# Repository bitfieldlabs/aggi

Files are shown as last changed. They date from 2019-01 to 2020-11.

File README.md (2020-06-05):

afterglow Afterglow GI

AFTERGLOW GI is a WPC pinball machine extension board that aims at softening the hard light on/off transitions that result in replacing the original GI incandescent bulbs with LEDs.

The brain of the board is a Arduino nano. It monitors the triac signals on the WPC bus and adjusts the PWM of the GI lines accordingly in order to dim the LEDs. For this purpose the whole GI is powered on DC voltage as opposed to the original AC 6.3V.

There are two options to power the Afterglow GI board and all GI LEDs:

:open_file_folder: [afterglow_gi_nano](https://github.com/bitfieldlabs/aggi/tree/master/afterglow_gi_nano)<br>
Board revision 1.0 needs to be powered from an external power supply. Recommended is a 12V supply delivering at least 8A.

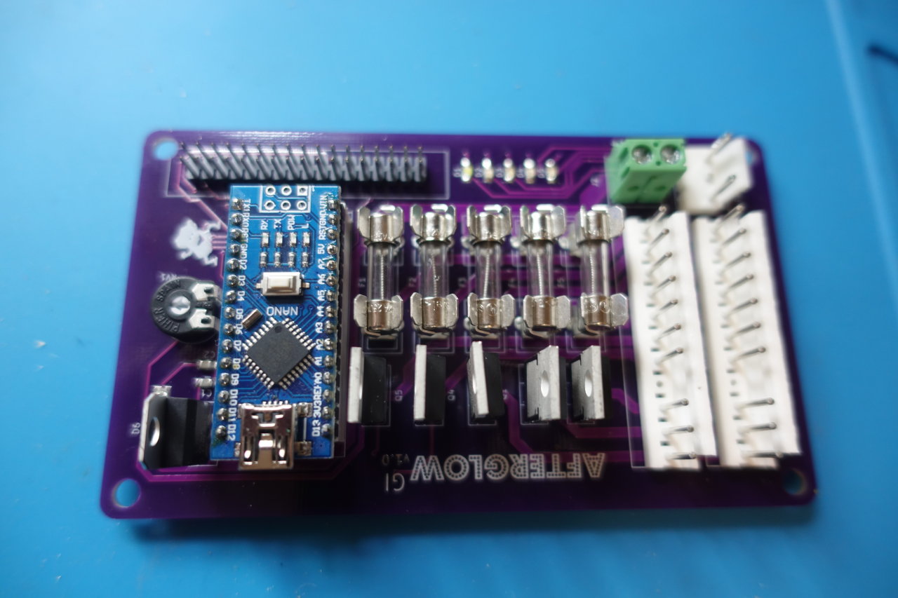
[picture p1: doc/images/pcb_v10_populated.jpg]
afterglow GI Afterglow GI v1.0


:open_file_folder: [afterglow_gi_nano_ps](https://github.com/bitfieldlabs/aggi/tree/master/afterglow_gi_nano_ps)<br>
Board revision 1.1 features a power supply and can be attached to the WPC power supply's 6.3V AC connector directly.

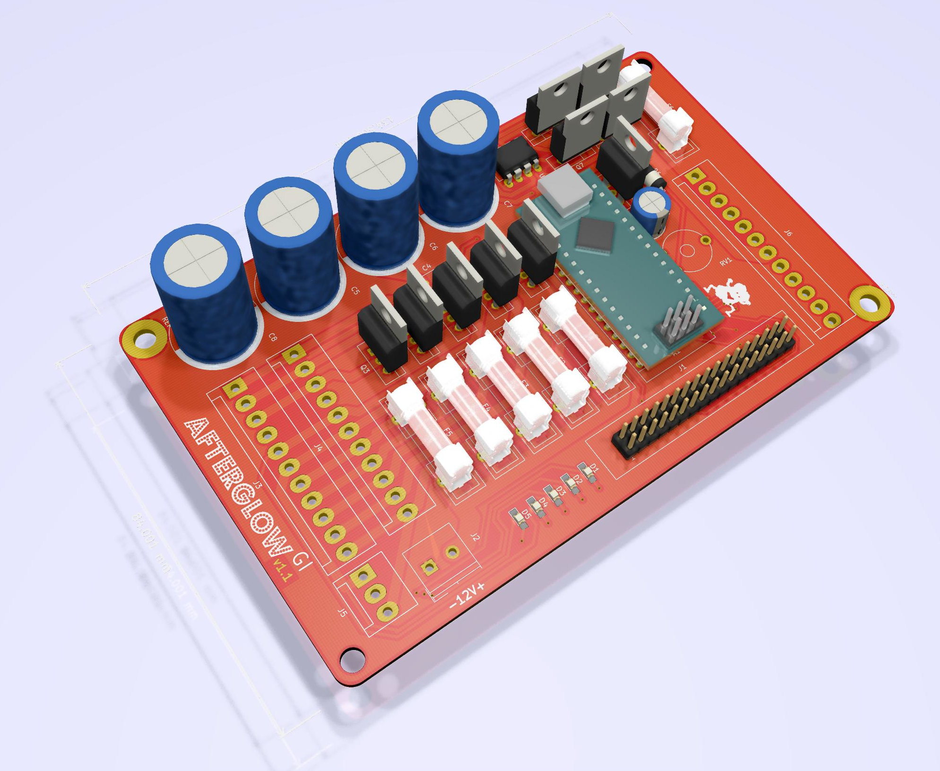
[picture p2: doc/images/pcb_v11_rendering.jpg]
afterglow GI Afterglow GI v1.1


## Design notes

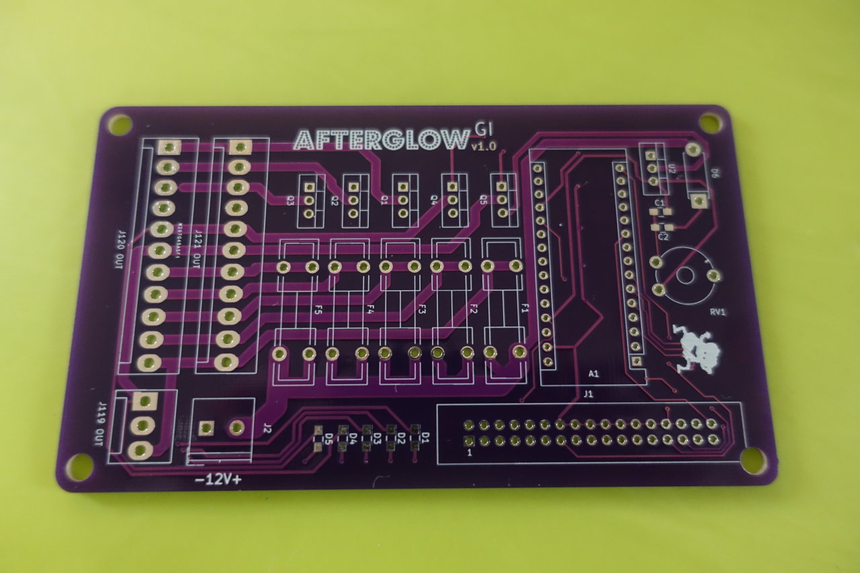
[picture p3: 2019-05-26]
doc/images/pcb_v10_unpopulated.jpg

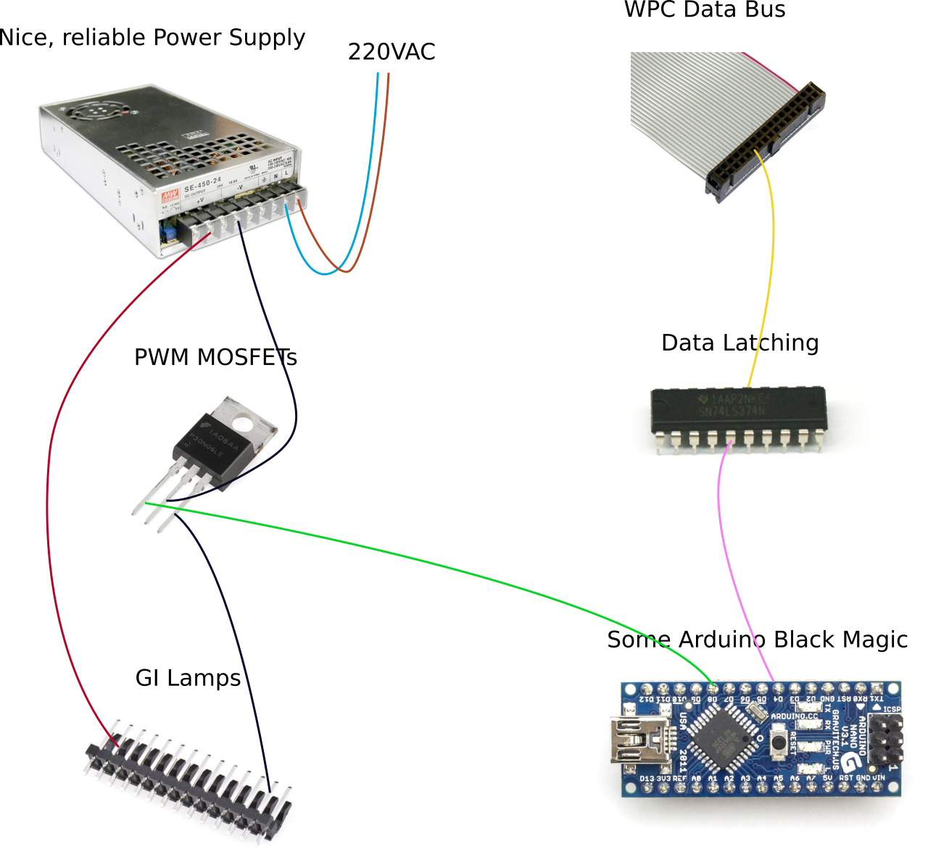
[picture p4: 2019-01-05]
doc/idea.png

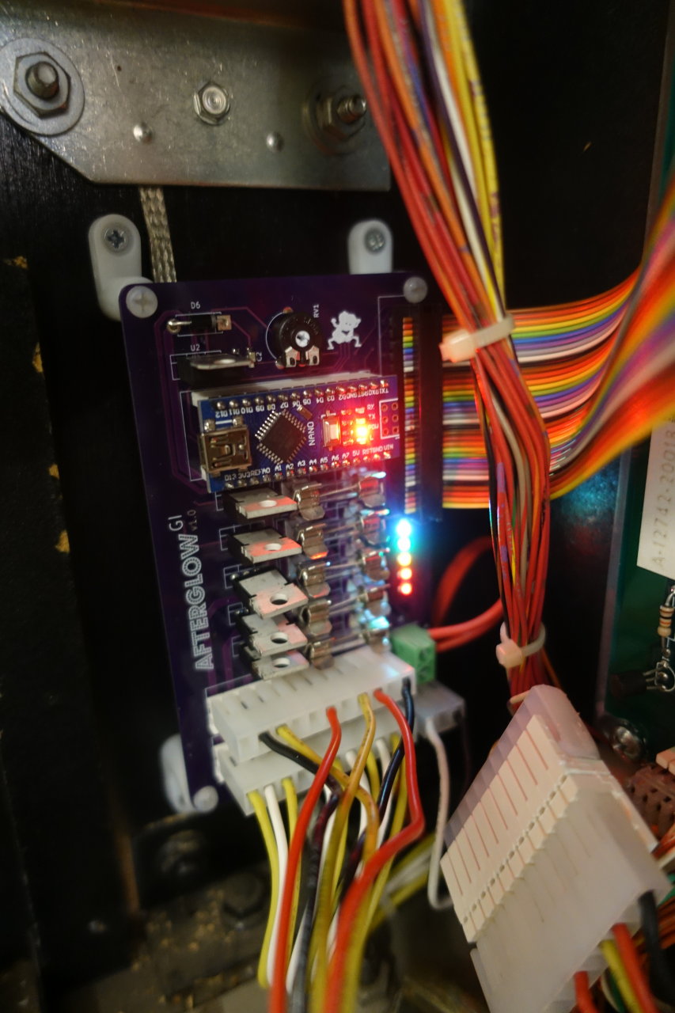
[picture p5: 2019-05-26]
doc/images/pcb_v10_mounted_1.jpg

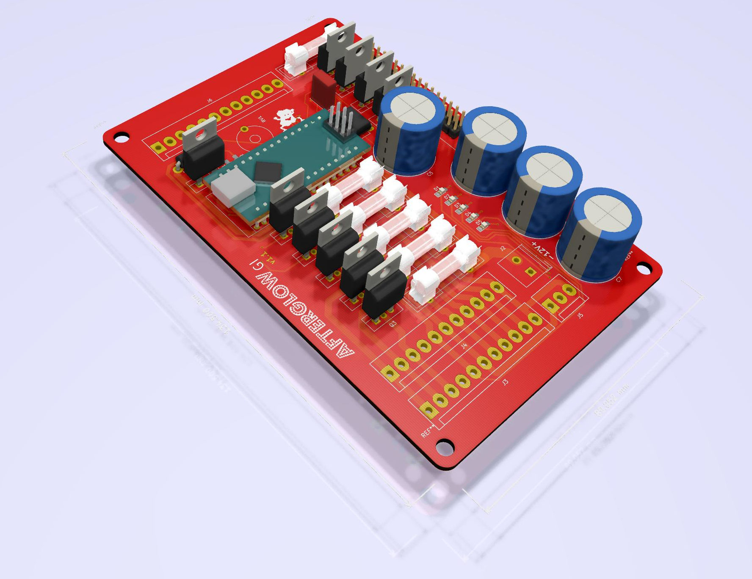
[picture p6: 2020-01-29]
doc/afterglow_gi_nano_ps.jpg

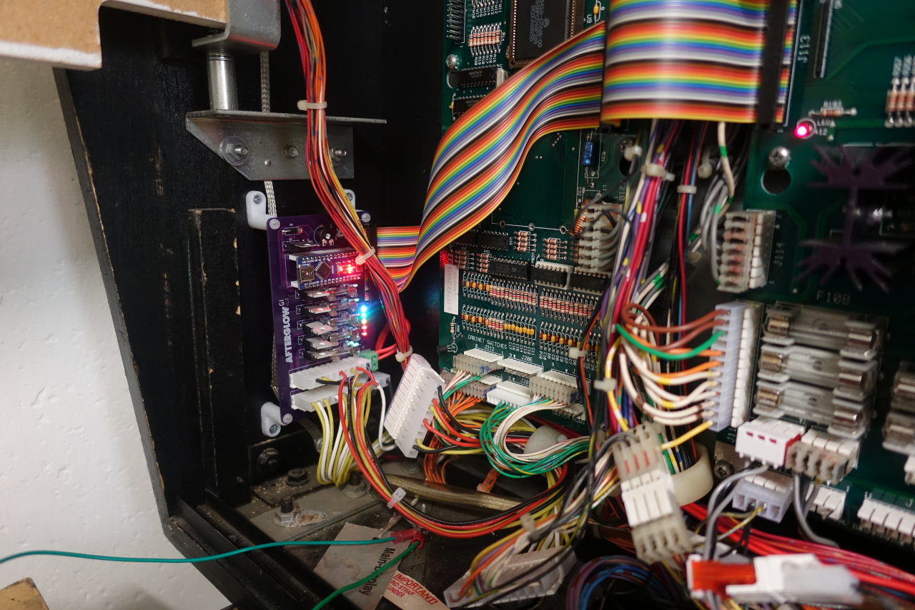
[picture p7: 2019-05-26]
doc/images/pcb_v10_mounted_2.jpg

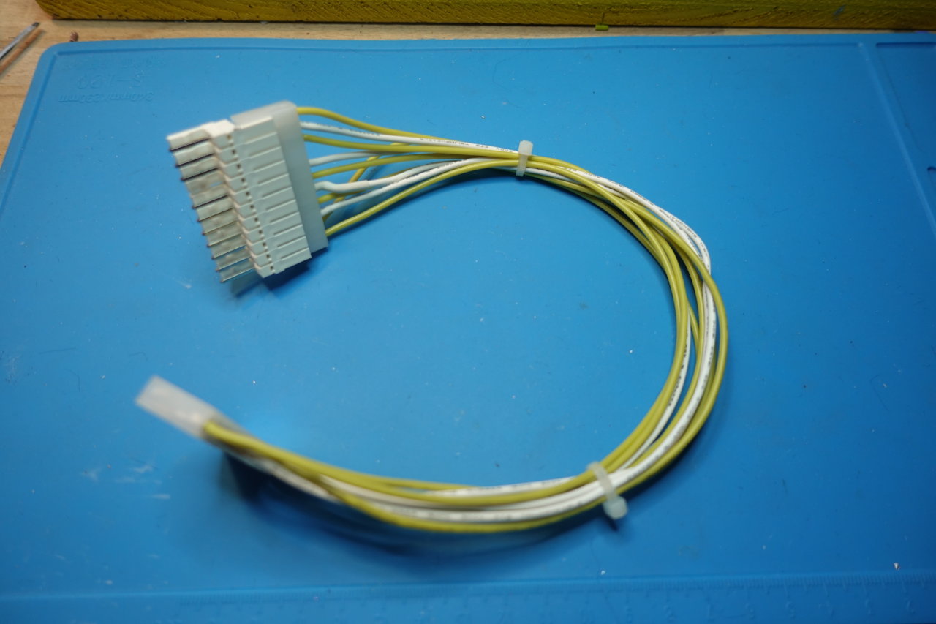
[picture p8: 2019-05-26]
doc/images/cable_extension_11pin_with_zconnector.jpg

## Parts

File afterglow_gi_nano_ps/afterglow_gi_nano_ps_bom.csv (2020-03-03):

Id | Designator | Package | Quantity | Designation | Supplier and ref
1 | C9 | CP_Radial_D8.0mm_P3.50mm | 1 | 100uF
2 | REF**,REF** | MountingHole_4.3mm_M4_Pad | 2 | MountingHole_4.3mm_M4_Pad
3 | C4 | C_Rect_L7.0mm_W3.5mm_P5.00mm | 1 | 1uF
4 | U3 | DIP-8_W7.62mm_LongPads | 1 | LT4320_CAP
5 | Q9,Q8,Q7,Q6,Q1,Q2,Q3,Q4,Q5 | TO-220_Vertical | 9 | FQP30N06L
6 | J6 | Molex_KK-41791-12_10x3.96mm_Straight | 1 | Conn_01x12_Male
7 | F6,F1,F2,F3,F4,F5 | Fuseholder5x20_horiz_open_lateral_Type-II | 6 | Fuse
8 | C8,C7,C6,C5 | CP_Radial_D18.0mm_P7.50mm | 4 | 5600uF
9 | , | MountingHole_4.3mm_M4_DIN965 | 2 | MountingHole_4.3mm_M4_DIN965
10 | RV1 | Potentiometer_Trimmer_Piher_PT-10v10_Horizontal_Px10.0mm_Py5.0mm | 1 | R_POT_TRIM
11 | J2 | TerminalBlock_Philmore_TB132_02x5mm_Straight | 1 | POWER_CONN
12 | U1 | SOIC-20W_7.5x12.8mm_Pitch1.27mm | 1 | 74LS374
13 | A1 | Arduino_Nano | 1 | Arduino_Nano_v3.x
14 | C1 | C_0805_HandSoldering | 1 | C_Small
15 | C2 | C_0805_HandSoldering | 1 | 0.33u
16 | C3 | C_0805_HandSoldering | 1 | 0.1u
17 | D1,D2,D3,D4,D5 | LED_0805_HandSoldering | 5 | LED
18 | D6 | D_5W_P10.16mm_Horizontal | 1 | D
19 | J1 | IDC_Header_Straight_34pins | 1 | Conn_02x17_Odd_Even
20 | J3 | Molex_KK-41791-11_10x3.96mm_Straight | 1 | GI_WPC_J120
21 | J4 | Molex_KK-41791-11_10x3.96mm_Straight | 1 | GI_WPC_J121
22 | J5 | Molex_KK-41791-03_03x3.96mm_Straight | 1 | GI_CONN_J119
23 | R1,R3,R5,R6,R8,R9,R11,R12,R14,R15,R17 | R_0805_HandSoldering | 11 | 10k
24 | R2 | R_0805_HandSoldering | 1 | 1.5k
25 | R4,R7,R10,R13,R16,R21,R22 | R_0805_HandSoldering | 7 | 220
26 | R18,R19,R20 | R_0805_HandSoldering | 3 | 180
27 | R23 | R_0805_HandSoldering | 1 | 1M
28 | R24 | R_0805_HandSoldering | 1 | 300k
29 | U2 | TO-220_Vertical | 1 | L7805
30 | FLAKIE | FLAKIE_inv | 1
31 | afterglow | afterglow | 1

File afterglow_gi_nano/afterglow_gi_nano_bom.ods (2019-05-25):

Source: | /home/smyp/data/elektronikbaschtel/aggi/afterglow_gi_nano/afterglow_gi_nano.sch
Date: | So 05 Mai 2019 08:55:42 CEST
Tool: | Eeschema 5.1.2
Generator: | /usr/share/kicad/plugins/bom_csv_grouped_by_value_with_fp.py
Component Count: | 52
Ref | Qnty | Value | Description
A1, | 1 | Arduino_Nano_v3.x | Arduino Nano v3.x
C1, | 1 | 0.1u | Unpolarized capacitor, small symbol
C2, | 1 | 0.33u | Unpolarized capacitor, small symbol
C3, | 1 | 0.1u | Unpolarized capacitor, small symbol
D1, D2, D3, D4, D5, | 5 | LED | Light emitting diode
D6, | 1 | D | Diode
F1, F2, F3, F4, F5, | 5 | Fuse | Fuse
J1, | 1 | Conn_02x17_Odd_Even | Generic connector, double row, 02x17, odd/even pin numbering scheme (row 1 odd numbers, row 2 even numbers), script generated (kicad-library-utils/schlib/autogen/connector/)
J2, | 1 | POWER_CONN | Generic connector, single row, 01x02, script generated (kicad-library-utils/schlib/autogen/connector/)
J3, | 1 | GI_WPC_J120 | Generic connector, single row, 01x11, script generated (kicad-library-utils/schlib/autogen/connector/)
J4, | 1 | GI_WPC_J121 | Generic connector, single row, 01x11, script generated (kicad-library-utils/schlib/autogen/connector/)
J5, | 1 | GI_CONN_J119 | Generic connector, single row, 01x03, script generated (kicad-library-utils/schlib/autogen/connector/)
Q1, Q2, Q3, Q4, Q5, | 5 | FQP30N06L | MOSFET N-CH 60V 32A TO-220
R1, R5, R3, R8, R6, R11, R9, R14, R12, R17, R15, | 11 | 10k | Resistor
R2, | 1 | 1.5k | Resistor
R18, R19, R20, | 3 | 180 | Resistor
R21, R22, R4, R7, R10, R13, R16, | 7 | 220 | Resistor
R23, | 1 | 1M | Resistor
R24, | 1 | 300k | Resistor
RV1, | 1 | R_POT_TRIM | Trim-potentiometer
U1, | 1 | 74LS374 | 8-bit Register, 3-state outputs
U2, | 1 | L7805 | Positive 1.5A 35V Linear Regulator, Fixed Output 5V, TO-220/TO-263/TO-252

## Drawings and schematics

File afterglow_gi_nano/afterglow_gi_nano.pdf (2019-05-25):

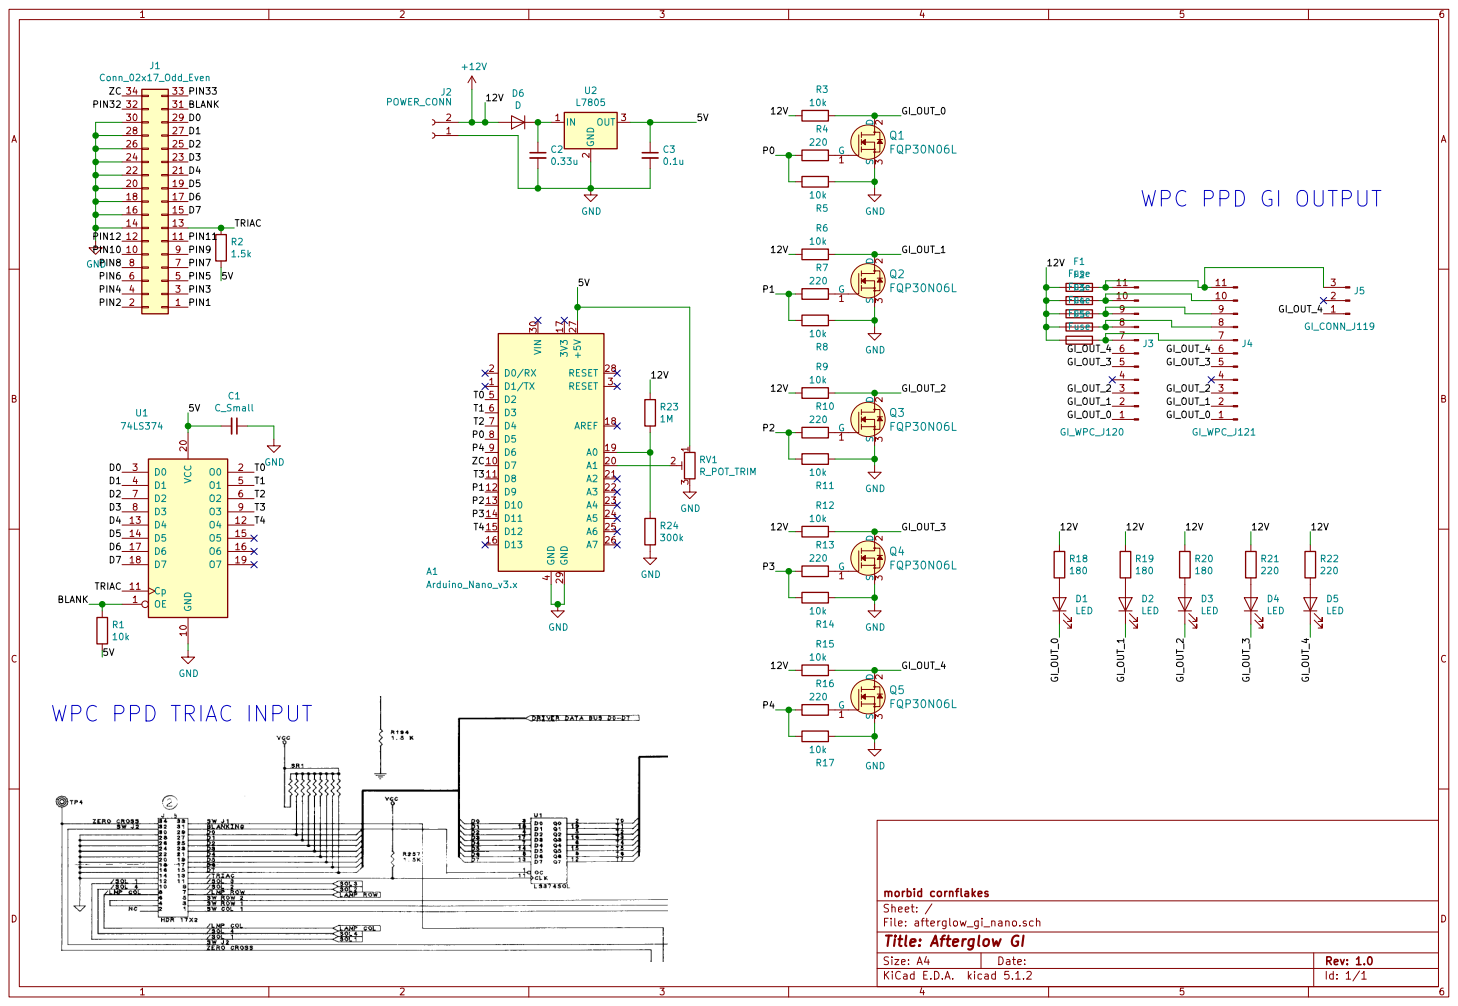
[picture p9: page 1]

ZC GND 26 | 25

24 | 23
22 | 21
20 | 19
18 | 17

WPC PPD GI OUTPUT

F2 Fuse F3 Fuse F4 Fuse F5 Fuse

4 D2 5 D3 6 D4 7 D5 8 D6 9 A1Arduino_Nano_v3.x OE 1 GND 10
P0P1P2P3P4 WPC PPD TRIAC INPUT
D0 D1 D2 D3 D4 D5 D6 D7 BLANK

File: afterglow_gi_nano.sch Sheet: / morbid cornflakes

Id: 1/1 Title: Afterglow GI

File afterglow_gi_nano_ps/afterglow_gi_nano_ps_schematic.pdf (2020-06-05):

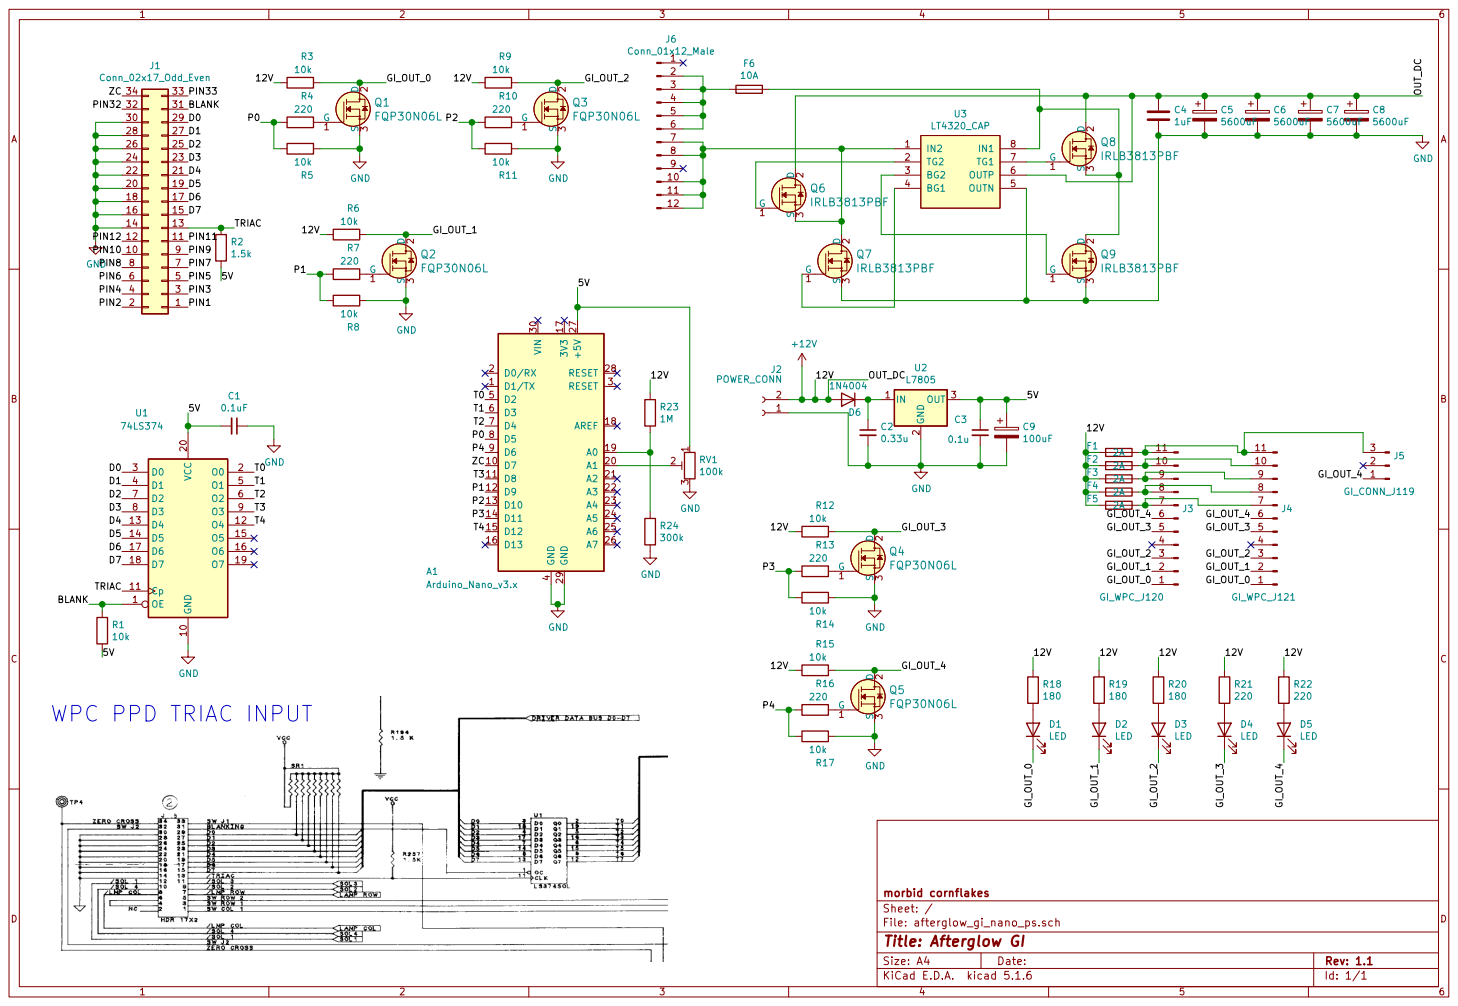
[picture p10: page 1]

J6 Conn_01x12_Male
P0 WPC PPD TRIAC INPUT

22 | 21
20 | 19
18 | 17
16 | 15
14 | 13

File: afterglow_gi_nano_ps.sch Sheet: / morbid cornflakes

Id: 1/1 Title: Afterglow GI

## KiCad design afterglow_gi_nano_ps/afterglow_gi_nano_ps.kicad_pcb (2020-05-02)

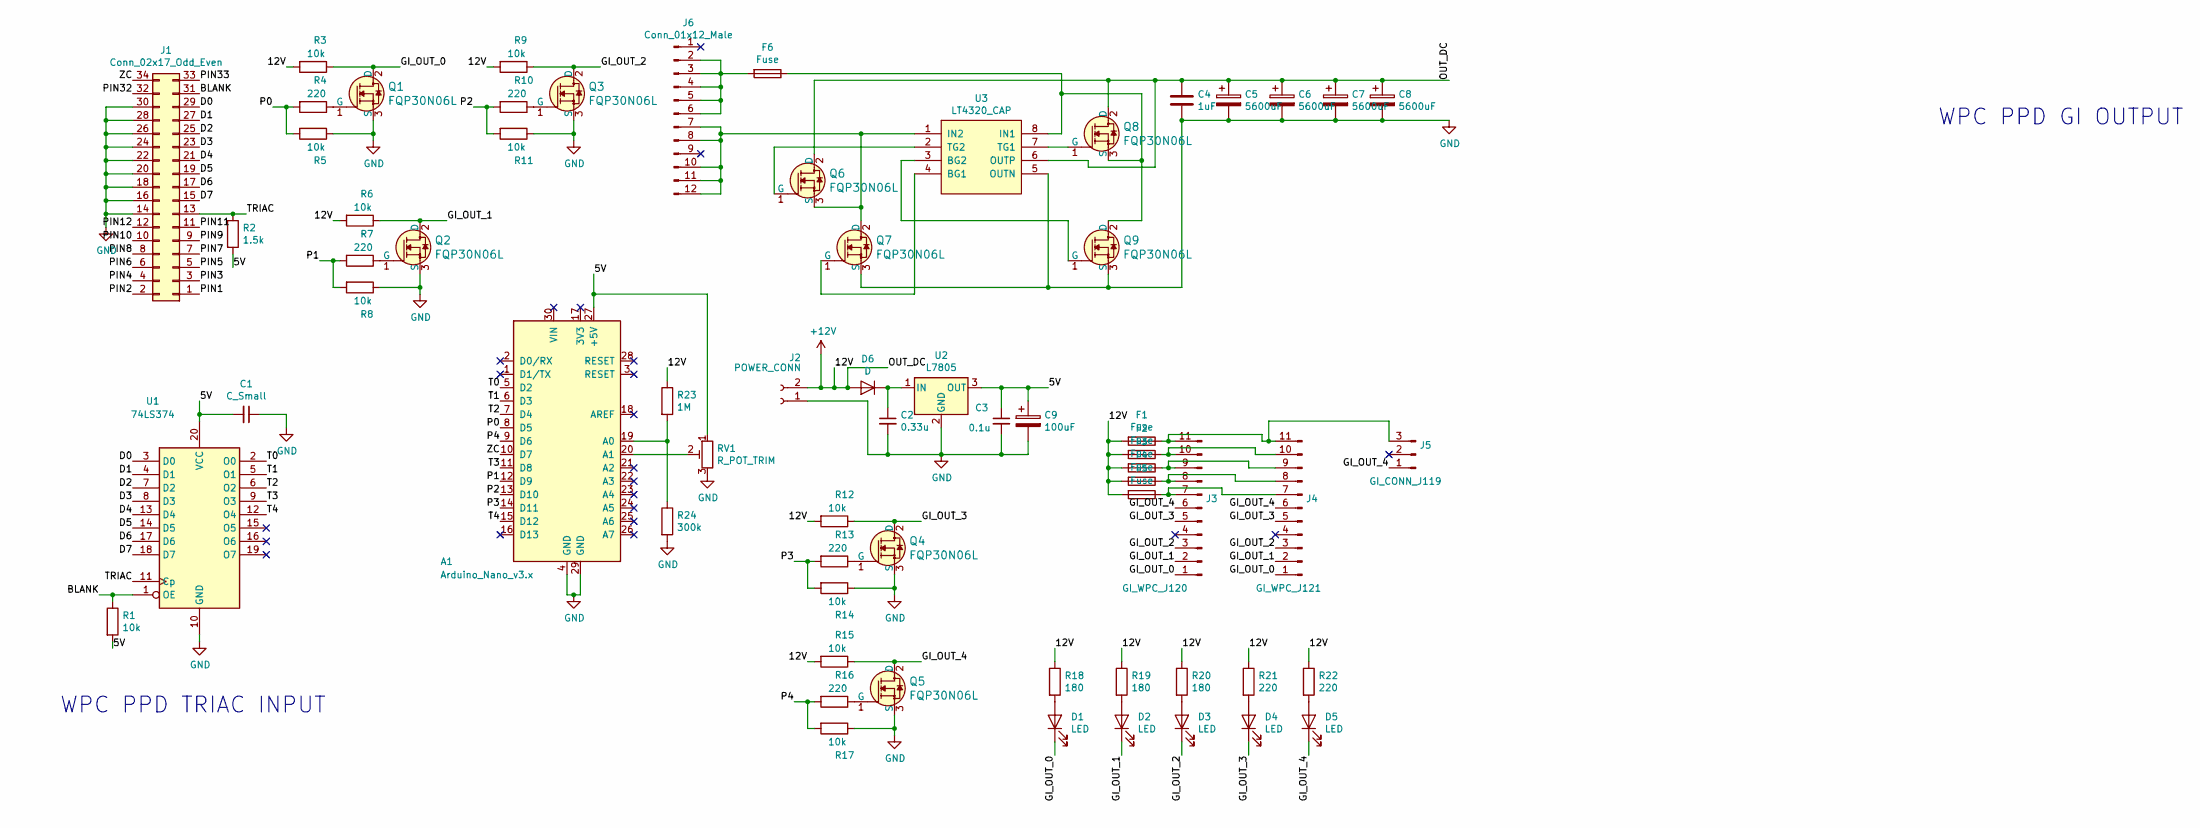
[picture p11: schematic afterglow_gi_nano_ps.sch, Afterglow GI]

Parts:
A1: Arduino_Nano_v3.x; Arduino_Nano
C1: C_Small; C_0805_HandSoldering
C2: 0.33u; C_0805_HandSoldering
C3: 0.1u; C_0805_HandSoldering
C4: 1uF; C_Rect_L7.0mm_W3.5mm_P5.00mm
C5, C6, C7, C8: 5600uF; CP_Radial_D18.0mm_P7.50mm
C9: 100uF; CP_Radial_D8.0mm_P3.50mm
D1, D2, D3, D4, D5: LED; LED_0805_HandSoldering
D6: D; D_5W_P10.16mm_Horizontal
F1, F2, F3, F4, F5, F6: Fuse; Fuseholder5x20_horiz_open_lateral_Type-II
J1: Conn_02x17_Odd_Even; IDC_Header_Straight_34pins
J2: POWER_CONN; TerminalBlock_Philmore_TB132_02x5mm_Straight
J3: GI_WPC_J120; Molex_KK-41791-11_10x3.96mm_Straight
J4: GI_WPC_J121; Molex_KK-41791-11_10x3.96mm_Straight
J5: GI_CONN_J119; Molex_KK-41791-03_03x3.96mm_Straight
J6: Conn_01x12_Male; Molex_KK-41791-12_10x3.96mm_Straight
Q1, Q2, Q3, Q4, Q5, Q6, Q7, Q8, Q9: FQP30N06L; TO-220_Vertical; MPN FQP30N06L; Digi-Key_PN FQP30N06L-ND
R1, R3, R5, R6, R8, R9, R11, R12, R14, R15, R17: 10k; R_0805_HandSoldering
R2: 1.5k; R_0805_HandSoldering
R4, R7, R10, R13, R16, R21, R22: 220; R_0805_HandSoldering
R18, R19, R20: 180; R_0805_HandSoldering
R23: 1M; R_0805_HandSoldering
R24: 300k; R_0805_HandSoldering
RV1: R_POT_TRIM; Potentiometer_Trimmer_Piher_PT-10v10_Horizontal_Px10.0mm_Py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
U1: 74LS374; SOIC-20W_7.5x12.8mm_Pitch1.27mm
U2: L7805; TO-220_Vertical
U3: LT4320_CAP; DIP-8_W7.62mm_LongPads

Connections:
+12V: C4.1, C5.1, C6.1, C7.1, C8.1, D6.2 (A), F1.2, F2.2, F3.2, F4.2, F5.2, J2.2, Q6.2 (D), Q8.2 (D), R3.2, R6.2, R9.2, R12.2, R15.2, R18.1, R19.1, R20.1, R21.1, R22.1, R23.1, U3.6 (OUTP)
/5V: A1.27 (+5V), C1.2, C3.1, C9.1, R1.2, R2.2, RV1.1, U1.20 (VCC), U2.3 (OUT)
/BLANK: J1.31, R1.1, U1.1 (OE)
/D0: J1.29, U1.3 (D0)
/D1: J1.27, U1.4 (D1)
/D2: J1.25, U1.7 (D2)
/D3: J1.23, U1.8 (D3)
/D4: J1.21, U1.13 (D4)
/D5: J1.19, U1.14 (D5)
/D6: J1.17, U1.17 (D6)
/D7: J1.15, U1.18 (D7)
/GI_OUT_0: D1.1 (K), J3.1, J4.1, Q1.2 (D), R3.1
/GI_OUT_1: D2.1 (K), J3.2, J4.2, Q2.2 (D), R6.1
/GI_OUT_2: D3.1 (K), J3.3, J4.3, Q3.2 (D), R9.1
/GI_OUT_3: D4.1 (K), J3.5, J4.5, Q4.2 (D), R12.1
/GI_OUT_4: D5.1 (K), J3.6, J4.6, J5.1, Q5.2 (D), R15.1
/P0: A1.8 (D5), R4.2, R5.2
/P1: A1.12 (D9), R7.2, R8.2
/P2: A1.13 (D10), R10.2, R11.2
/P3: A1.14 (D11), R13.2, R14.2
/P4: A1.9 (D6), R16.2, R17.2
/PIN1: J1.1
/PIN2: J1.2
/PIN3: J1.3
/PIN4: J1.4
/PIN5: J1.5
/PIN6: J1.6
/PIN7: J1.7
/PIN8: J1.8
/PIN9: J1.9
/PIN10: J1.10
/PIN11: J1.11
/PIN12: J1.12
/PIN32: J1.32
/PIN33: J1.33
/T0: A1.5 (D2), U1.2 (O0)
/T1: A1.6 (D3), U1.5 (O1)
/T2: A1.7 (D4), U1.6 (O2)
/T3: A1.11 (D8), U1.9 (O3)
/T4: A1.15 (D12), U1.12 (O4)
/TRIAC: J1.13, R2.1, U1.11 (Cp)
/ZC: A1.10 (D7), J1.34
GND: A1.4 (GND), A1.29 (GND), C1.1, C2.2, C3.2, C4.2, C5.2, C6.2, C7.2, C8.2, C9.2, J1.14, J1.16, J1.18, J1.20, J1.22, J1.24, J1.26, J1.28, J1.30, J2.1, Q1.3 (S), Q2.3 (S), Q3.3 (S), Q4.3 (S), Q5.3 (S), Q7.3 (S), Q9.3 (S), R5.1, R8.1, R11.1, R14.1, R17.1, R24.2, RV1.3, U1.10 (GND), U2.2 (GND), U3.5 (OUTN)
unnamed: A1.19 (A0), R23.2, R24.1
unnamed: A1.20 (A1), RV1.2
unnamed: C2.1, D6.1 (K), U2.1 (IN)
unnamed: D1.2 (A), R18.2
unnamed: D2.2 (A), R19.2
unnamed: D3.2 (A), R20.2
unnamed: D4.2 (A), R21.2
unnamed: D5.2 (A), R22.2
unnamed: F1.1, J3.11, J4.11, J5.3
unnamed: F2.1, J3.10, J4.10
unnamed: F3.1, J3.9, J4.9
unnamed: F4.1, J3.8, J4.8
unnamed: F5.1, J3.7, J4.7
unnamed: F6.1, Q8.3 (S), Q9.2 (D), U3.8 (IN1)
unnamed: F6.2, J6.2, J6.3, J6.4, J6.5, J6.6
unnamed: J6.7, J6.8, J6.10, J6.11, J6.12, Q6.3 (S), Q7.2 (D), U3.1 (IN2)
unnamed: Q1.1 (G), R4.1
unnamed: Q2.1 (G), R7.1
unnamed: Q3.1 (G), R10.1
unnamed: Q4.1 (G), R13.1
unnamed: Q5.1 (G), R16.1
unnamed: Q6.1 (G), U3.2 (TG2)
unnamed: Q7.1 (G), U3.4 (BG1)
unnamed: Q8.1 (G), U3.7 (TG1)
unnamed: Q9.1 (G), U3.3 (BG2)

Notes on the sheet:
WPC PPD TRIAC INPUT
WPC PPD GI OUTPUT

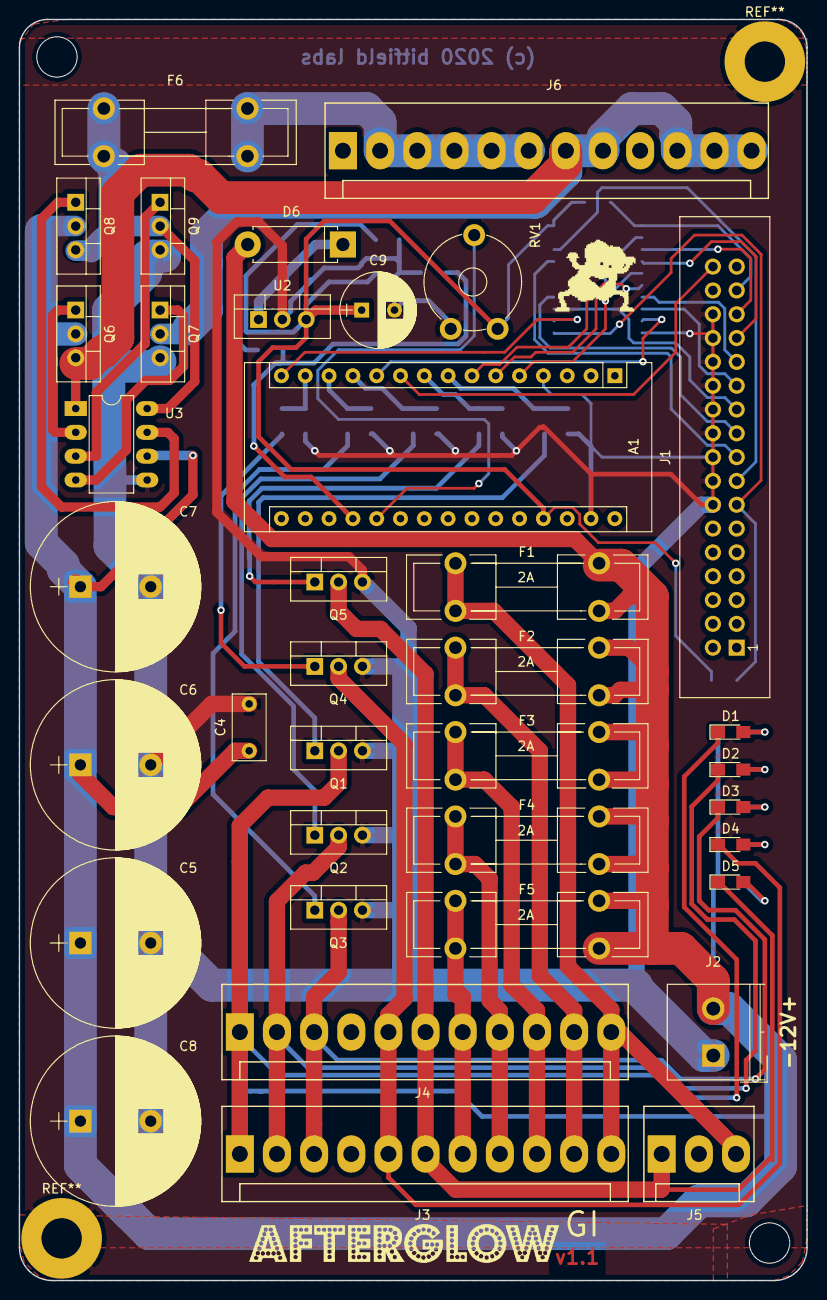
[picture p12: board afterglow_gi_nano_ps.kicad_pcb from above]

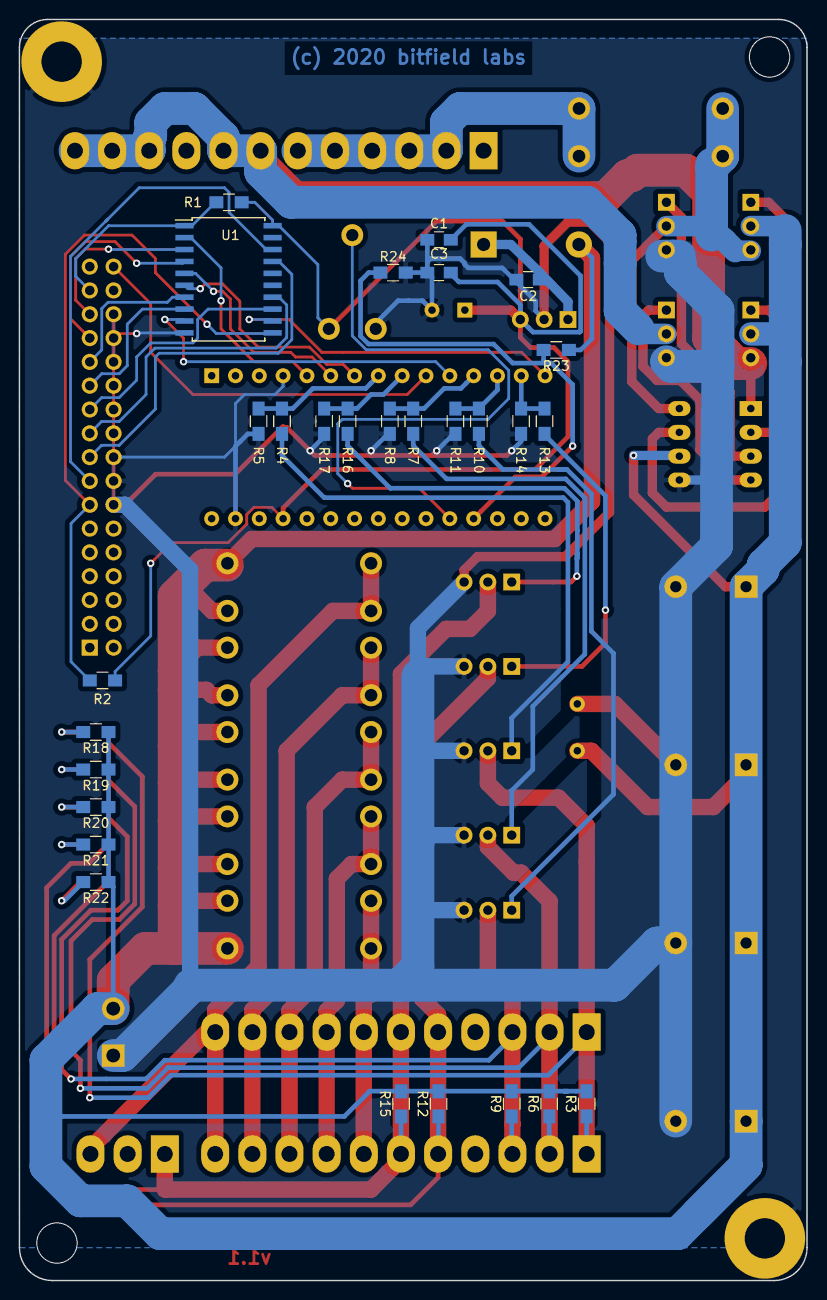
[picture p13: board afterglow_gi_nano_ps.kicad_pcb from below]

Board: 2 copper layers, 84.0 x 134.5 mm, 67 parts (28 on the bottom side), 54 nets.

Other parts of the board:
FLAKIE: FLAKIE_inv
afterglow: afterglow

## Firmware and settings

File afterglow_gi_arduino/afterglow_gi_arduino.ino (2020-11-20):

/***********************************************************************
 *  Afterglow GI:
 *      Copyright (c) 2019 Christoph Schmid
 *
 ***********************************************************************
 *  This file is part of the Afterglow GI pinball LED project:
 *  https://github.com/smyp/afterglow_gi
 *
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
 *  You should have received a copy of the GNU Lesser General Public
 *  License along with Afterglow GI.
 *  If not, see <http://www.gnu.org/licenses/>.
 ***********************************************************************/
 
//------------------------------------------------------------------------------
/* This code assumes following pin layout:
 *
 *  +----------+---------------+-----------+---------------+--------------+
 *  | Name     | Function      | Nano Pin# | Register, Bit | Mode         |
 *  +----------+---------------+-----------+---------------+--------------+
 *  | STR1_IN  | D0 Data Bus   | D2        | DDRD, 2       | Input        |
 *  | STR2_IN  | D1 Data Bus   | D3        | DDRD, 3       | Input        |
 *  | STR3_IN  | D2 Data Bus   | D4        | DDRD, 4       | Input        |
 *  | STR4_IN  | D3 Data Bus   | D8        | DDRB, 0       | Input        |
 *  | STR5_IN  | D4 Data Bus   | D12       | DDRB, 4       | Input        |
 *  | ZC       | Zero Crossing | D7        | DDRD, 7       | Input        |
 *  | STR1_OUT | STR 1 PWM     | D5        | DDRD, 5       | Output       |
 *  | STR2_OUT | STR 2 PWM     | D9        | DDRB, 1       | Output       |
 *  | STR3_OUT | STR 3 PWM     | D10       | DDRB, 2       | Output       |
 *  | STR4_OUT | STR 4 PWM     | D11       | DDRB, 3       | Output       |
 *  | STR5_OUT | STR 5 PWM     | D6        | DDRD, 6       | Output       |
 *  | V_MEAS   | Voltage Meas  | A0        | DDRC, 0       | Analog Input | 
 *  | POT      | Potentiometer | A1        | DDRC, 1       | Analog Input |
 *  +----------+---------------+-----------+---------------+--------------+
*/

#include <EEPROM.h>
#include <avr/wdt.h>
#include <avr/boot.h>

//------------------------------------------------------------------------------
// Setup

// Afterglow GI version number
#define AFTERGLOW_GI_VERSION 101

// Afterglow GI board revision. Currently v1.1.
#define BOARD_REV 11

// turn debug output via serial on/off
#define DEBUG_SERIAL 1

// voltage measurement pin
#define V_MEAS_PIN A0

// local time interval (us)
#define TTAG_INT 1024

// Number of GI strings
#define NUM_STRINGS 5

// Number of brightness steps
#define NUM_BRIGHTNESS 8

// PWM resolution (given by the Arduino HW)
#define PWM_NUM_STEPS 255

// Number of center brightness values required to switch value
#define BRIGHTNESS_SWITCH_THRESH 5

// Brightness interval margin to account for overlapping intervals [us]
#define BRIGHTNESS_INTERVAL_MARGIN 150

// Uncertain brightness value
#define BRIGHTNESS_UNCERTAIN 255

// Brightness interpolation duration [2^n ms, e.g. 8=256ms]
#define BRIGHTNESS_INTERPOL_DURBITS 8

// Brightness interpolation steps (2^n, e.g. 3=8 steps)
#define BRIGHTNESS_INTERPOL_STEPBITS 3

// Duration of an interpolation step [2^n ms]
#define BRIGHTNESS_INTERPOL_INTBITS (BRIGHTNESS_INTERPOL_DURBITS - BRIGHTNESS_INTERPOL_STEPBITS)

// Default input voltage (12V)
#define INPUT_VOLTAGE_DEFAULT 120

// Measure the input voltage (if set to 1)
// If disabled the hardcoded default voltage (INPUT_VOLTAGE_DEFAULT) is used
#define MEASURE_VOLTAGE 1


//------------------------------------------------------------------------------
// global variables

// local time
static volatile uint32_t sTtag = 0;

static byte sLastPIND = 0;
static byte sLastPINB = 0;
static uint32_t sDataIntLast[NUM_STRINGS] = {0};
static uint8_t sBrightnessN[NUM_STRINGS] = {0};
static uint32_t sZCIntTime = 0;
static uint8_t sInterruptsSeen = 0;
static volatile uint8_t sBrightness[NUM_STRINGS] = {0};
static volatile uint8_t sBrightnessTarget[NUM_STRINGS] = {0};
static volatile uint32_t sBrightnessLastUpd[NUM_STRINGS] = {0};
static volatile uint8_t sBrightnessIntLastStep[NUM_STRINGS];
static volatile uint8_t sBrightnessHist[NUM_STRINGS][NUM_BRIGHTNESS+1] = {0}; // including 0 for 'off'
static volatile uint32_t sBrightnessPot = 0;

static uint8_t sDutyCycleTable[NUM_BRIGHTNESS+1] = {0}; // including 0 for 'off'
static uint8_t sVoltage = INPUT_VOLTAGE_DEFAULT;

#if DEBUG_SERIAL
static volatile uint32_t sMinDt[NUM_STRINGS] = {0};
static volatile uint32_t sMaxDt[NUM_STRINGS] = {0};
#endif


//------------------------------------------------------------------------------
void setup()
{
    // Use Timer1 to create an interrupt every TTAG_INT us.
    // This will be the heartbeat of our realtime task.
    noInterrupts(); // disable all interrupts
    TCCR1B = 0;

    // set compare match register for TTAG_INT us increments
    // prescaler is at 64, so counting 64 x real clock cycles
    OCR1A = (TTAG_INT / 16);  // [16MHz x 64 (prescaler) clock cycles]
    // turn on CTC mode
    TCCR1B |= (1 << WGM12);
    // Set CS10 and CS11 bits to set prescaler to 64
    TCCR1B |= (1 << CS10);
    TCCR1B |= (1 << CS11);
    // enable timer compare interrupt
    TIMSK1 |= (1 << OCIE1A);

    // I/O pin setup
    // D2-D4, D7-D8 and D12 are inputs
    DDRD &= B01100011;
    DDRB &= B11101110;
    // D5, D6 and D9-D11 are outputs, pull them low
    DDRC |= B01100000;
    DDRB |= B00001110;
    PORTC &= B10011111;
    PORTB &= B11110001;

    // activate pin change interrupts on D2-D4, D7-D8 and D12 (interrupt masks 0 and 2)
    PCICR |= 0b00000101;
    PCMSK0 |= 0b00010001; // D8 and D12
    PCMSK2 |= 0b10011100; // D2-D4 and D7
    // clear any outstanding interrupts
    PCIFR = 0;

    // enable serial output at 115200 baudrate
    Serial.begin(115200);
    Serial.print("Afterglow GI v");
    Serial.print(AFTERGLOW_GI_VERSION);
    Serial.println(" (c) 2019 morbid cornflakes");
    // check the extended fuse for brown out detection level
    uint8_t efuse = boot_lock_fuse_bits_get(GET_EXTENDED_FUSE_BITS);
    Serial.println("-----------------------------------------------");
    uint8_t bodBits = (efuse & 0x7);
    Serial.print("efuse BOD ");
    Serial.println((bodBits == 0x07) ? "OFF" : (bodBits == 0x04) ? "4.3V" : (bodBits == 0x05) ? "2.7V" : "1.8V");

#if MEASURE_VOLTAGE
    // measure the input voltage
    sVoltage = measureInputVoltage();
    Serial.print("Input voltage ");
    Serial.println(sVoltage);
#endif

    // populate the duty cycle table
    populateDutyCycleTable(sVoltage);

    // initialize data
    memset((void*)sBrightnessIntLastStep, 255, sizeof(sBrightnessIntLastStep));

    // read the global brightness (potientometer) value
    sBrightnessPot = analogRead(A1);

    // enable all interrupts
    interrupts();

    // enable a strict 15ms watchdog
    //wdt_enable(WDTO_15MS);
}

//------------------------------------------------------------------------------
// Timer1 interrupt handler
// This is the realtime task heartbeat. All the output magic happens here.
ISR(TIMER1_COMPA_vect)
{
    // Time is ticking
    sTtag++;

    // Update all GI strings
    updateGI();

    // Kick the dog
    //wdt_reset();

}

//------------------------------------------------------------------------------
void newBrightness(uint8_t string, uint8_t b)
{
    // Check whether the brightness has changed
    if (b <= NUM_BRIGHTNESS)
    {
        // Add the current brightness value to the histogram
        if (sBrightnessHist[string][b] < 0xff)
        {
            sBrightnessHist[string][b]++;
        }

        // Only switch when some measurements in the center of the
        // brightness interval have been seen
        if (sBrightnessHist[string][b] > BRIGHTNESS_SWITCH_THRESH)
        {
            if (b != sBrightnessTarget[string])
            {
                // abort current interpolation if not done yet
                sBrightness[string] = sBrightnessTarget[string];
    
                // switch to the new brightness target value
                sBrightnessTarget[string] = b;
                sBrightnessLastUpd[string] = sTtag;
            }

            // clear the histogram
            memset((void*)&(sBrightnessHist[string][0]), 0, NUM_BRIGHTNESS+1);
        }
    }
}

//------------------------------------------------------------------------------
void handlePinChange(uint32_t t, uint8_t newPinMask, uint8_t pinBit, uint8_t string)
{
    // Measure and store the time since the last zero crossing interrupt
    if (newPinMask & pinBit)
    {
        // Handle only once
        uint32_t dtLast = (t - sDataIntLast[string]);
        if (dtLast > 1000)
        {
            uint8_t stringBit = (1<<string);
            uint32_t dt = (t - sZCIntTime);
            if (dt < 10000)
            {
                // Translate delta time into brightness
                uint8_t b = dtToBrightness(dt);

                // Handle the new brightness value
                newBrightness(string, b);

#if DEBUG_SERIAL
                if ((dt < sMinDt[string]) || (sMinDt[string] == 0)) sMinDt[string] = dt;
                if (dt > sMaxDt[string]) sMaxDt[string] = dt;
#endif
            }
            sDataIntLast[string] = t;
            sInterruptsSeen |= stringBit;
        }
    }
}

//------------------------------------------------------------------------------
void handlePinInterrupts()
{
    // The WPC CPU issues a short signal to turn on the triac controlling the
    // AC voltage. The Triac will stay on until the next zero crossing of the
    // AC signal.
    // The closer the signal is to the zero crossing, the brighter the lamps
    // will be. If no signal is issued at all (stays high), the lamps will light
    // at full power. If the signal remains low, the lamps are turned off.
    // The zero crossing signal is issued with twice the AC frequency, i.e. with
    // 100Hz or every 10ms in Europe.
    // The scope says the ZC signal is 1ms long while the Triac signal is only
    // ~8us long.

    // ZC Sig          TR Sig        ZC Sig          ZC     Zero Crossing Signal
    // |                |            |               TR     Triac enable signal
    // |--+  |  |  |  | v|  |  |  |  |--+            B0-B6  Brightness 1-7 levels (WPC GI)
    // |ZC|                          |ZC|
    // |  |B7 B6 B5 B4 B3 B2 B1      |  |
    // +-----------------------------+------
    // 0ms                           10ms

    // Check which pins triggered this interrupt
    byte newPinB = (sLastPINB ^ PINB);
    sLastPINB = PINB;
    byte newPinD = (sLastPIND ^ PIND);
    sLastPIND = PIND;

    // What time is it?
    uint32_t t = micros();

    if (newPinD & B10000000) // ZC on D7
    {
        // Handle zero crossing interrupts

        // The zero crossing signal should appear at 100Hz. If we're closer to
        // last interrupt then this is the falling edge and we should ignore it.
        if ((t - sZCIntTime) > 4000)
        {
            // Just remember the last zero crossing interrupt time
            sZCIntTime = t;

            // All strings without interrupt in the past interval are either fully
            // on or off
            if ((sInterruptsSeen & 0x01) == 0) newBrightness(0, (PIND & 0B00000100) ? 0: NUM_BRIGHTNESS);
            if ((sInterruptsSeen & 0x02) == 0) newBrightness(1, (PIND & 0B00001000) ? 0: NUM_BRIGHTNESS);
            if ((sInterruptsSeen & 0x04) == 0) newBrightness(2, (PIND & 0B00010000) ? 0: NUM_BRIGHTNESS);
            if ((sInterruptsSeen & 0x08) == 0) newBrightness(3, (PINB & 0B00000001) ? 0: NUM_BRIGHTNESS);
            if ((sInterruptsSeen & 0x10) == 0) newBrightness(4, (PINB & 0B00010000) ? 0: NUM_BRIGHTNESS);
    
            // Clear the interrupts mask
            sInterruptsSeen = 0;
        }
    }

    // Handle all strings
    handlePinChange(t, newPinD, B00000100, 0); // String 0 on D2
    handlePinChange(t, newPinD, B00001000, 1); // String 1 on D3
    handlePinChange(t, newPinD, B00010000, 2); // String 2 on D4
    handlePinChange(t, newPinB, B00000001, 3); // String 3 on D8
    handlePinChange(t, newPinB, B00010000, 4); // String 4 on D12
}

//------------------------------------------------------------------------------
// Pin change interrupt on D2-D7 handler
// This is measuring the zero-crossing to blank signal time.
ISR(PCINT0_vect)
{
    // handle the interrupts
    handlePinInterrupts();
}

//------------------------------------------------------------------------------
// Pin change interrupt on D2-D7 handler
// This is measuring the zero-crossing to blank signal time.
ISR(PCINT2_vect)
{
    // handle the interrupts
    handlePinInterrupts();
}

//------------------------------------------------------------------------------
void loop()
{
    // The main loop is used for low priority serial communication only.
    // All the fun stuff happens in the interrupt handlers.

    // Count the loops (used for debug output below)
    static uint32_t loopCounter = 0;
    loopCounter++;
#if DEBUG_SERIAL
    if ((loopCounter % 10) == 0)
    {
        Serial.print("T ");
        Serial.println(sTtag);
        Serial.print("ZC - ");
        Serial.print(sZCIntTime);
        Serial.println("us");
        Serial.print("Global Br ");
        Serial.println(sBrightnessPot);
        for (uint8_t i=0; i<NUM_STRINGS; i++)
        {
            Serial.print(i);
            Serial.print(" - ");
            Serial.print(sBrightness[i]);
            Serial.print(" min ");
            Serial.print(sMinDt[i]);
            Serial.print(" max ");
            Serial.println(sMaxDt[i]);
        }
	}
    if ((loopCounter % 100) == 0)
    {
        for (uint8_t i=0; i<NUM_STRINGS; i++)
        {
            sMinDt[i] = sMaxDt[i] = 0;
        }
   }
#endif

    // wait 500ms
    delay(500);
}

//------------------------------------------------------------------------------
uint8_t dtToBrightness(uint32_t dt)
{
    // This function leaves some margin at the interval borders to account for
    // the fact the intervals are slightly overlapping and therefore a
    // unambiguous brightness determination is not always possible. In this case
    // the function returns 255.

    uint8_t b;
    if (dt < (1200-BRIGHTNESS_INTERVAL_MARGIN))
    {
        // full power, this shouldn't really happen
        b = NUM_BRIGHTNESS;
    }
    else if ((dt > (1200+BRIGHTNESS_INTERVAL_MARGIN)) &&
             (dt < (2200-BRIGHTNESS_INTERVAL_MARGIN)))
    {
        b = 6;
    }
    else if ((dt > (2200+BRIGHTNESS_INTERVAL_MARGIN)) &&
             (dt < (3200-BRIGHTNESS_INTERVAL_MARGIN)))
    {
        b = 5;
    }
    else if ((dt > (3200+BRIGHTNESS_INTERVAL_MARGIN)) &&
             (dt < (4200-BRIGHTNESS_INTERVAL_MARGIN)))
    {
        b = 4;
    }
    else if ((dt > (4200+BRIGHTNESS_INTERVAL_MARGIN)) &&
             (dt < (5200-BRIGHTNESS_INTERVAL_MARGIN)))
    {
        b = 3;
    }
    else if ((dt > (5200+BRIGHTNESS_INTERVAL_MARGIN)) &&
             (dt < (6200-BRIGHTNESS_INTERVAL_MARGIN)))
    {
        b = 2;
    }
    else if ((dt > (6200+BRIGHTNESS_INTERVAL_MARGIN)) &&
             (dt < (7200-BRIGHTNESS_INTERVAL_MARGIN)))
    {
        b = 1;
    }
    else
    {
        // invalid interval
        b = BRIGHTNESS_UNCERTAIN;
    }
    return b;
}

//------------------------------------------------------------------------------
void updateGI()
{
    static const uint8_t skPWMPins[NUM_STRINGS] = {5, 9, 10, 11, 6};

    // update all brightness values
    for (uint8_t i=0; i<NUM_STRINGS; i++)
    {
        if (sBrightness[i] != sBrightnessTarget[i])
        {
            uint32_t dt = (sTtag - sBrightnessLastUpd[i]);
            uint32_t step = (dt >> BRIGHTNESS_INTERPOL_INTBITS);
            int16_t b1 = 0;
            int16_t b2 = 0;
            uint8_t b;
            bool newB = false;
            if (step >= (1 << BRIGHTNESS_INTERPOL_STEPBITS))
            {
                // target brightness reached
                sBrightness[i] = sBrightnessTarget[i];
                sBrightnessIntLastStep[i] = 255;
                step = (1 << BRIGHTNESS_INTERPOL_STEPBITS);
                b = sDutyCycleTable[sBrightness[i]];
                newB = true;
            }
            else if (step != sBrightnessIntLastStep[i])
            {
                // Adjust the PWM if required
                b1 = sDutyCycleTable[sBrightness[i]];
                b2 = sDutyCycleTable[sBrightnessTarget[i]];
                int16_t diff = (b2 - b1);
                int16_t stepSize = (diff > 0) ? (diff >> BRIGHTNESS_INTERPOL_STEPBITS) : -((-diff) >> BRIGHTNESS_INTERPOL_STEPBITS);
                b = (uint8_t)(b1 + stepSize * step);
                newB = true;
                sBrightnessIntLastStep[i] = step;
            }

            // apply the new PWM value
            if (newB)
            {
                // scale the brightness with the potentiometer value
                uint8_t scaledB = (uint8_t)(((uint32_t)b * sBrightnessPot) >> 10);
                if ((scaledB == 0) && (b != 0))
                {
                    b = 1; // minimum brightness
                }
                else
                {
                    b = scaledB; // scaled brightness
                }

                // apply the PWM
                analogWrite(skPWMPins[i], b);
 #if DEBUG_SERIAL && 0
                if (i==1)
                {
                    Serial.print("[");
                    Serial.print(i);
                    Serial.print(" / ");
                    Serial.print(step);
                    Serial.print("] ");
                    Serial.print(sTtag);
                    Serial.print(" ");
                    Serial.print(dt);
                    Serial.print(" - ");
                    Serial.print(sBrightness[i]);
                    Serial.print(" (");
                    Serial.print(b1);
                    Serial.print(")");
                    Serial.print("->");
                    Serial.print(sBrightnessTarget[i]);
                    Serial.print(" (");
                    Serial.print(b2);
                    Serial.print(")");
                    Serial.print(" ");
                    Serial.println(b);
                }
#endif
            }
        }
    }
}

//------------------------------------------------------------------------------
void populateDutyCycleTable(uint8_t voltage)
{
    // Assume 6.3V LEDs with 3.2V drop -> 124 Ohm resistor for 25mA current
    uint32_t c = ((uint32_t)voltage - 32)*100/124;
    uint8_t dc = (uint8_t)(25 * 100 / c);
    uint8_t maxDC = (PWM_NUM_STEPS * dc / 100);

    Serial.print("CYCLE TABLE");

#if 0
    // linear distribution
    sDutyCycleTable[1] = 1; // darkest possible
    for (uint8_t i=2; i<=NUM_BRIGHTNESS; i++)
    {
        sDutyCycleTable[i] = ((i-1)*maxDC/(NUM_BRIGHTNESS-1));
    }
    Serial.println(" LIN");
#else
    // logarithmic distribution
    uint32_t r = (maxDC - 1);
    double m = log10(NUM_BRIGHTNESS);
    double s = 1.0/m;
    for (uint8_t i=1; i<=NUM_BRIGHTNESS; i++)
    {
        sDutyCycleTable[i] = 1 + r - floor(log10(NUM_BRIGHTNESS-i+1) * s * (double)r);
    }
    Serial.println(" LOG");
#endif

    // print the table
    Serial.print("max dc ");
    Serial.print(dc);
    Serial.print("% = ");
    Serial.print(maxDC);
    Serial.println("");
    for (uint8_t i=1; i<=NUM_BRIGHTNESS; i++)
    {
        Serial.print(i);
        Serial.print(" - ");
        Serial.println(sDutyCycleTable[i]);
    }
}

#if MEASURE_VOLTAGE
//------------------------------------------------------------------------------
uint8_t measureInputVoltage()
{
    // do some analog readings
    uint32_t v = 0;
    for (int i=0; i<10; i++)
    {
        int vmeas = analogRead(V_MEAS_PIN);
        v += vmeas;
#if DEBUG_SERIAL
        Serial.println(vmeas);
#endif
    }

    // take the average
    v /= 10;

    // convert to [0.1 volts]
    // respecting the 1MOhm/300kOhm voltage divider at the input
    // v has 10 bits [0..1023]
    // V_in = V_out * ((R1+R2)/R2) = V_out * 4.333
    v *= 100;
    v /= 472;

    // paranoia ckeck
    // force voltage to be between 8V and 15V
    if ((v<80) || (v>150))
    {
        // use default
#if DEBUG_SERIAL
        Serial.println("Forcing voltage to default voltage!");
#endif
        v = INPUT_VOLTAGE_DEFAULT;
    }
    
    return (uint8_t)v;
}
#endif

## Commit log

2019-01-04 Use the Arduino PWM pins
2019-01-04 PWM seems to work now
2019-01-05 Fixed an interrupt issue
    [afterglow_gi_arduino.ino]
2019-01-05 Started with the schematic
    [afterglow_gi_nano.kicad_pcb, afterglow_gi_nano.sch]
2019-01-06 Fixed brightness level 6
    [afterglow_gi_arduino.ino]
2019-01-06 Schematic progress
    [afterglow_gi_nano.sch]
2019-01-06 Schematic progressing
    [afterglow_gi_nano.kicad_pcb, afterglow_gi_nano.sch]
2019-02-18 Designing the PCB
    [afterglow_gi_nano.kicad_pcb, afterglow_gi_nano.sch]
2019-02-19 Some PCB progress
    [afterglow_gi_nano.kicad_pcb]
2019-02-24 First PCB draft complete
    [afterglow_gi_nano.kicad_pcb]
2019-02-24 PCB v1.00 ready
    [afterglow_gi_nano-B.Cu.gbr, afterglow_gi_nano-B.Mask.gbr, afterglow_gi_nano-B.Paste.gbr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]
2019-02-24 PCB cosmetics
    [afterglow_gi_nano-B.Cu.gbr, afterglow_gi_nano-B.Mask.gbr, afterglow_gi_nano-B.Paste.gbr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]
2019-05-25 Added schematic pdf and BOM
    [afterglow_gi_nano_bom.ods]
2020-01-08 Added footprint position files
2020-02-09 Added power supply schematic
    [afterglow_gi_nano_ps.kicad_pcb, afterglow_gi_nano_ps.sch]
2020-02-09 A PCB layout proposal
    [afterglow_gi_nano.kicad_pcb, afterglow_gi_nano.sch, afterglow_gi_nano_ps.kicad_pcb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]
2020-02-09 Some progress
    [afterglow_gi_nano_ps.kicad_pcb, afterglow_gi_nano_ps.sch]
2020-02-09 New PCB layout with power supply
    [afterglow_gi_nano_ps.kicad_pcb, afterglow_gi_nano_ps.sch]
2020-02-09 New power supply
    [afterglow_gi_nano_ps-B_Cu.gbl, afterglow_gi_nano_ps-B_Mask.gbs, afterglow_gi_nano_ps-B_Paste.gbp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]
2020-02-14 PCB cosmetix
    [afterglow_gi_nano_ps-B_Cu.gbl, afterglow_gi_nano_ps-B_Mask.gbs, afterglow_gi_nano_ps-B_Paste.gbp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]
2020-02-21 Added position files and BOM
    [afterglow_gi_nano_ps.sch, afterglow_gi_nano_ps_bom.csv]
2020-02-28 Added missing C4 footprint, grounding pads
    [afterglow_gi_nano_ps-B_Cu.gbl, afterglow_gi_nano_ps-B_Mask.gbs, afterglow_gi_nano_ps-B_Paste.gbp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]
2020-02-28 Added 5V stabilizing capacitor
    [afterglow_gi_nano_ps.kicad_pcb, afterglow_gi_nano_ps.sch]
2020-03-03 Added PS BOM and schematic
    [afterglow_gi_nano_ps.kicad_pcb, afterglow_gi_nano_ps.sch, afterglow_gi_nano_ps_bom.csv]
2020-05-02 Fixed a routing error around C4
    [afterglow_gi_nano_ps.kicad_pcb]
2020-06-02 Some labelling
    [afterglow_gi_nano_ps.sch]
2020-06-05 Upaded PCB v1.1 Gerber files
    [afterglow_gi_nano_ps-B_Cu.gbl, afterglow_gi_nano_ps-B_Mask.gbs, afterglow_gi_nano_ps-B_Paste.gbp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]
2020-06-05 Added a PCB v1.1 rendering
2020-11-20 Measure the input voltage

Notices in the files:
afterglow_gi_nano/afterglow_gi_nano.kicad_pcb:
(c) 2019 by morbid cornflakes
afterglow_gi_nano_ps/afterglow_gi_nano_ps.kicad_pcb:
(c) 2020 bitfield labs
